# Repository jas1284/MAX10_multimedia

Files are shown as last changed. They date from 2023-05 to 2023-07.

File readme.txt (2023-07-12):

Uncompressed* Audio and Video playback on DE10-lite MAX10 FPGA board.
Requires an arduino shield with microSD slot via SPI.
(UIUC ECE385 SP23 final project)

DEMO VIDEO:
https://youtu.be/Ck-EtcvA4ko

HOW TO USE THIS PROJECT
Compile and run with Quartus Prime Lite 18.1.
Simply open FP-ZUOFU-BASIC.qsf and compile. "player_toplevel" should be top level.
Program the FPGA, no eclipse needed because no NIOS. (Custom I2C module inits the SGTL5000!)

Load in your SDcard and hit reset. Enjoy!

Controls:
- KEY0 is reset/reload. Press this button if you change out the SDcard or switch between audio and video modes (SW9).
   - The FPGA will first buffer half of the SDRAM, and then begin playback. The rest is loaded while playing.
   - While buffering, HEX5:HEX0 will display the address being buffered to. 
- KEY1 is volume adjust. It adjusts volume circularly, and works by writing to the SGTL's registers.
- SW1: set 1 to listen to audio playback, set 0 to listen to audio passthru from line in. 
- SW9: set 1 to play y4m video, set 0 to play wav audio.

Outputs:
- LEDR 9,8 indicate SDcard buffer load status. When both lit, the SDCard has stopped writing to buffer since it's half is done.
    - If only LEDR9 is on, this indicates that the buffer has been overrun, and the video playback will probably loop in a bit.
    - This is because the ping-pong buffer only allows writes to the half that reads are NOT being read from.
- LEDR 7,6 are debug indicators for video playback.

Loading a file to SDCARD
- Make sure you are using an SDHC card.
- Download and install HXD - run it as administrator (following step may fail otherwise)
- Open the SDcard as a RAW DISK (tools, open disk, physical disks - uncheck readonly)

VIDEO: Use the .bat file included. Needs FFMPEG, available online.
- Open the output.y4m in HxD
- CTRL-A the contents of output.y4m, paste it to the SDCard at address 0.
- Copy starting from the first "FRAME" of output.y4m, and paste it starting at address 0x59.
   - "F" of "FRAME" should be at 0x59.
   - Playback will work if you do not do this step (my code is flexible), 
      but the SDRAM ping-pong buffer may run erratically and fail to buffer in time.
      - The SDCARD throughput bottleneck is real!
      - My guess is that the SDcard's delays when moving from one block to the next happen to occur
        at lucky times when starting from 0x59, while starting anywhere else leads to unlucky delay timing 
        that ultimately results in not refilling the buffer in time. 
- Ctrl-S to save to the SDcard - this may take a while.
- Eject the card, put it in the FPGA, set SW9 to 1, hit reset, enjoy.
- Slow SDcards may not be fast enough for video playback even with the 0x59 start. 
- SANDISK EXTREME 32GB were our card of choice, but they were only barely just fast enough.
    - Old SANDISK 32GB ULTRA PLUS was ever so slightly too slow for video, but plenty fast for audio.
HEX0 will show format being detected:
- 4: y4m (YUV420P, 176x144 @ 24fps)
- 1: H.261 (incomplete/inoperable, sadly)
HEX5:HEX1 will show the current leftmost contents of the playback shift-register.

AUDIO: Open your desired file in Audacity, export in one of 3 WAV formats @ 44.1khz:
- 16bit signed PCM
- "U-law" (8bits mapping to 14bits)
- "A-law" (8bits mapping to 13bits)

- Open the file in HxD
- Ctrl-A the contents and paste it to SDCARD at address 0.
(No special offsets needed here - audio bitrate is low and forgiving.)
- Ctrl-S to save the contents to the card. This may take a moment.
- Eject the card, put it in the FPGA, set sw9 to 0, hit reset, enjoy. Plug in VGA for visualizer!
- FPGA auto-detects the playback format. 
HEX0 will show what it's detecting:
- 1: 16-bit signed PCM (stereo)
- 2: U-law (stereo)
- A: A-law (stereo)
HEX5:HEX1 will show what the current playback address[23:4] in memory is.

.VOX VOX ADPCM and MONO IMA-ADPCM in WAV are both experimental and very rough support. 
Playback amplitude erratic but the sound is identifiable.

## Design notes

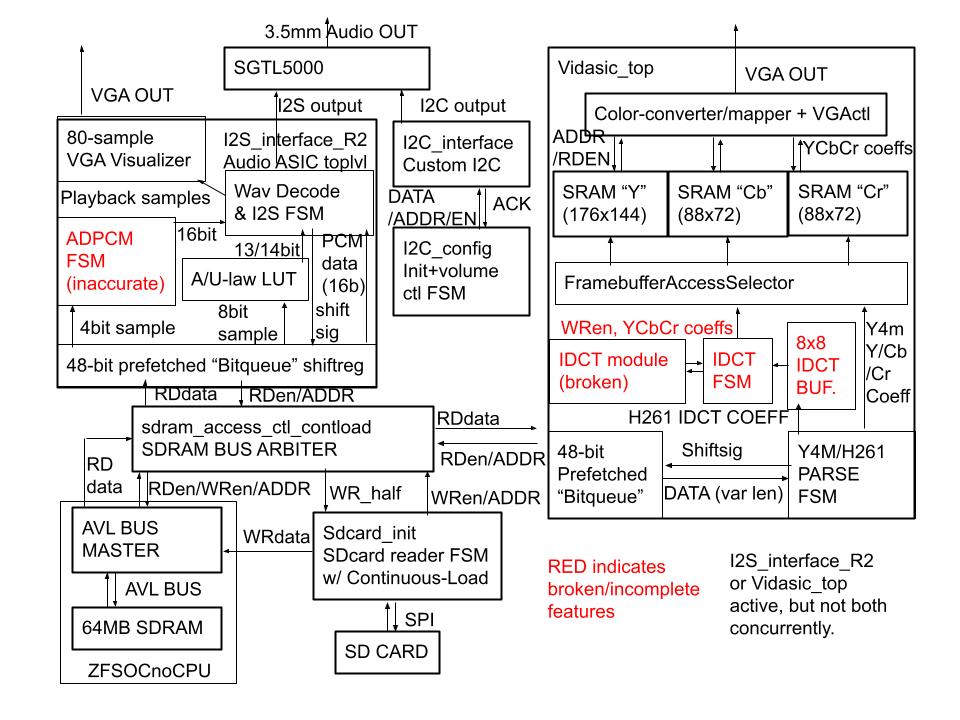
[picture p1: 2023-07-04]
BlockDiagram.jpg

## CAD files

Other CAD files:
stp2.stp
stp3.stp
stp1.stp

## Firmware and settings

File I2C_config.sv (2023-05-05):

// Module for storing and writing the intial configurations for the audio registers on the SGTL5000 and continually updating volume
// Takes input of clk, reset, an acknowledge from the I2C_interface, and a switch or button. Upon program startup or reset, it will
// write to the registers so that audio is outputting from I2S to HP out, and it will continue to loop, updating volume through switch
// input and writing it to the register on the SGTL5000.

module I2C_config (
	input  logic clk50,
	input  logic reset,
	
	output logic [15:0] i2c_address,
	output logic [15:0] i2c_data,
	output logic interface_enable,
	
	input  logic interface_acknowledge,	
	
	//volume:
	input  logic SW1
	);
	
	
	logic [3:0] counter_state = 0;
	logic interface_acknowledge_state = 0;
	
	logic SW1_state = 1;
	logic ack_state = 0;
	
	logic [5:0] clk50_counter = 0;
	logic [5:0] pulselength = 50;
	logic [6:0] volume = 0;
	
	//just trigger 
	always_ff @ (posedge clk50) begin
		counter_state <= counter_state;
		interface_enable <= 1'b0;
		volume <= volume;
		//need rising edge of interface_acknowledge and being within correct range to increment/output data
		if(interface_acknowledge == 1'b1 && interface_acknowledge_state == 1'b0 && counter_state < 12) begin
			interface_acknowledge_state <= 1'b1;
			interface_enable <= 1'b1;
		end
		//cycle through all the states (each state is just data to output for config
		if(interface_acknowledge == 1'b0 && interface_acknowledge_state == 1'b1) begin
			if(counter_state < 11) begin
				counter_state <= counter_state + 1;
			end//last state loops and constantly writes the value of volume to the I2C config
			interface_acknowledge_state <= 1'b0;
		end
		
		if(reset) begin //resets state to 0 and restarts the config cycle
			interface_acknowledge_state <= 1'b0;
			counter_state <= 0;
			interface_enable <= 1'b0;
		end
		
		if(SW1 == 1 && SW1_state == 0) begin //switch edge detection for volume value update
			SW1_state <= 1;
			if(volume >= 120) begin
				volume <= 0;
			end
			else begin
				volume <= volume + 20;
			end
		end
		
		if(SW1 == 0 && SW1_state == 1) begin
			SW1_state <= 0;
		end
	end
	
	
	
	//i2c_address and i2c_data output
	//See datasheet and report for specifics of what each write does, for the most part it is the same as provided code
	//except changing a few minor values like # of bits per cycle
	always_comb begin
		i2c_address = 16'h0000;
		i2c_data = 16'h0000;
		case (counter_state) 
			1: begin
				//CHIP_PLL_CTRL register: 739b 
				i2c_address = 16'h0032;
				i2c_data = 16'h739b;
			end
			2: begin
				//CHIP_ANA_POWER register: 45fe
				i2c_address = 16'h0030;
				i2c_data = 16'h45fe;
			end
			3: begin
				//CHIP_REF_CTRL register: 4e
				i2c_address = 16'h0028;
				i2c_data = 16'h004e;
			end
			4: begin
				//CHIP_DIG_POWER register: 63
				i2c_address = 16'h0002;
				i2c_data = 16'h0063;
			end
			5: begin
				//CHIP_CLK_CTRL register: 7
				i2c_address = 16'h0004;
				i2c_data = 16'h0007;
			end
			6: begin
				//CHIP_I2S_CTRL register: b0
				i2c_address = 16'h0006;
				i2c_data = 16'h00b0;
			end
			7: begin
				//CHIP_ANA_CTRL register: 4
				i2c_address = 16'h0024;
				i2c_data = 16'h0004;
			end
			8: begin
				//CHIP_SSS_CTRL register: 10
				i2c_address = 16'h000a;
				i2c_data = 16'h0010;
			end
			9: begin
				//CHIP_ADCDAC_CTRL register: 0
				i2c_address = 16'h000e;
				i2c_data = 16'h0000;
			end
			10: begin
				//CHIP_PAD_STRENGTH register: 555f
				i2c_address = 16'h0014;
				i2c_data = 16'h555f;
			end
			11: begin//volume, continuously write at this address
				i2c_address = 16'h0022; 
				i2c_data = {1'b0, volume, 1'b0, volume};
			end
			default: ;
		endcase
	end
	
	
	
/*
address <= 32'h0022;
				byte_enable <= 4'b1111;
				write <= 1'b1;
				write_data <= ((volume << 8) || volume);
*/
endmodule

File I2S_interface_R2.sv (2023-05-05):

/*
-------------
Upon being enabled, I2S_interface will start reading a raw PCM data
from given starting address and using it to output formatted I2S 
as required by the SGTL5000.
-------------
*/
module I2S_interface_R2 (
	input 	logic clk50,
	input 	logic reset,
	// input 	logic run,
	//inputs for muxing
	
	output 	logic [24:0]	ADDR_PRGM, //address for read to program. Formatted as 1 address space per 16 bits.
	input  	logic [15:0]	RDdata_PRGM, //data for read to program
	output 	logic RDen,					 //read enable from program. 
	input 	logic avalon_bridge_acknowledge,
	
	
	output logic I2S_DIN, //data input
	input  logic I2S_LRCLK, //frame clock (input from master mode, 44.1 kHz)
	input  logic I2S_SCLK, //bit clock (input from master mode, 64 * frame  clk rate)
	
	
	input  logic ADDR_load, // enable loading ADDR_start, not implemented for now
	input  logic I2S_enable,
	input  logic [24:0] ADDR_start, //address to start sequentially reading from, not implemented for now
	output logic [3:0] hex_out_5,
    output logic [3:0] hex_out_4,
	output logic [3:0] hex_out_3,
	output logic [3:0] hex_out_2,
	output logic [3:0] hex_out_1,
	output logic [3:0] hex_out_0,
	output logic [3:0] red,
    output logic [3:0] green,
    output logic [3:0] blue,
    output logic hsync,
    output logic vsync
	);
	
	// logic LRCLK_state; //used to determine when LRCLK changes edge for reading
	// logic [5:0]  load_counter; //  = 5'b11111; 
	// logic [15:0] RDdata_buffer; // = 0; //to store result after a read
	// logic [24:0] ADDR_current; // = 25'h13C;	//0
	// logic [4:0]  write_counter; //  = 16;
	// logic endian = 1;
	
	// assign hex_out_0 = READ_ADDR[3:0];
	assign hex_out_1 = READ_ADDR[7:4];
	assign hex_out_2 = READ_ADDR[11:8];
	assign hex_out_3 = READ_ADDR[15:12];
	assign hex_out_4 = READ_ADDR[19:16];
	assign hex_out_5 = READ_ADDR[23:20];

	parameter BIT_DEPTH = 16;	// Assume this much, lol. We don't have a good way to deal with it otherwise!
	parameter VOLUME_SHIFT = 1; // how many bits to shift to preserve hearing?

	enum logic [12:0] 
    {q_shift, 
    q_shift_release, 
    q_prefetch,
    q_prefetch_release,
    q_load1, 
    q_load1_wait, 
    q_load2, 
    q_load2_wait, 
    q_load3, 
    q_load3_wait
    } queue_state, q_nextstate;

	logic [24:0]    READ_ADDR, READ_ADDR_NEXT;  // current address of read from buffer.
	// logic [15:0]    READ_WORD;  // word to load into queue
	logic [5:0]     SHIFTCOUNT, SHIFTCOUNT_NEXT; // keeps track of how many shifts happened.
	logic [47:0]    BITQUEUE, BITQ_NEXT;    // queue of bits coming in
	logic Q_RDY; // Is the queue safe to read from? 

	// Values for Ram buffering logic
	logic RAM_DATA_BUFFER_EN; // Flag for enabling the RAM_DATA_BUFFER.
	// logic RAM_DATA_RDEN;	// RDEN for the ram buffering logic... synonymous with the state it seems
	reg RAM_DATA_BUFFER_STATE; // Buffered state for operation of RAM data buffer. 
	logic [15:0]    RAM_BUFFERED_READBACK;

	// Ram readback buffering mechanism - makes sure we don't miss data.
	always_ff @ (posedge clk50 or posedge reset)
	begin
		if(reset)
		begin
			// RAM_DATA_RDEN <= 1'b0;
			RAM_BUFFERED_READBACK <= 16'h0;
			RAM_DATA_BUFFER_STATE <= 1'b0;  // state: inactive
		end
		else if(RAM_DATA_BUFFER_STATE)  // If active state...
		begin
			// RAM_DATA_RDEN <= 1'b1;
			if(avalon_bridge_acknowledge) begin
				RAM_BUFFERED_READBACK <= RDdata_PRGM;
				RAM_DATA_BUFFER_STATE <= 1'b0; // go back to inactive/unarmed state.
			end
		end
		else	// Inactive state
			// RAM_DATA_RDEN <= 1'b0;
			RAM_DATA_BUFFER_STATE <= RAM_DATA_BUFFER_EN;    // Wait to be activated.
	end

	logic RDEN_override;
	// assign RAM_DATA_RDEN = RAM_DATA_BUFFER_STATE;
	assign RDen = (RAM_DATA_BUFFER_STATE |RDEN_override);

	always_ff @ (posedge clk50 or posedge reset)
	begin
		if(reset)
		begin
			BITQUEUE <= 48'h0;
			SHIFTCOUNT <= 6'h0;
			queue_state <= q_load3;
			READ_ADDR <= 25'h00;    // 0x0A gets us to byte d20, which determines datatype
		end
		else if(I2S_enable)
		begin
			BITQUEUE <= BITQ_NEXT;
			SHIFTCOUNT <= SHIFTCOUNT_NEXT;
			queue_state <= q_nextstate;
			READ_ADDR <= READ_ADDR_NEXT;
		end
	end

	always_comb 
	begin
		// default values: 
		BITQ_NEXT = BITQUEUE;       // queue doesnt move
		READ_ADDR_NEXT = READ_ADDR; // addr doesnt change
		SHIFTCOUNT_NEXT = SHIFTCOUNT;   // shift-counter stays
		ADDR_PRGM = READ_ADDR;       // Pre-set the ram address
		RDEN_override = 1'b0; 
		q_nextstate = queue_state;  // stay in current state
		// status_1 = 1'b0;    // lights - blank em 
		// status_2 = 1'b0;
		Q_RDY = 1'b0;   // Assume the queue's NOT READY unless otherwise stated.
		RAM_DATA_BUFFER_EN = 1'b0;  // Ram buffering mechanism assumes no incoming data.
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

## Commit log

2023-04-19 SDRAM access state machine, janky prefetched bit-queue, and groundwork for beginning to interpret the bitstream
    [stp1.stp]
2023-04-20 loading up to first TCOEFF
    [stp1.stp]
2023-04-24 audio smashed on but not really functional, will re-write
    [stp1.stp, stp2.stp]
2023-04-25 rewrote I2S interface to actually work
    [stp2.stp]
2023-04-25 buggy implementation, audio queue desyncs
    [sdcard_init.sv]
2023-04-26 temp pause... circular buffer screwed up
    [stp2.stp]
2023-04-26 stabilized audio output, by relying on slightly less questionable logic
    [stp2.stp]
2023-04-26 added bit-shift volume parameter to preserve eardrums
    [stp2.stp]
2023-04-27 SDRAM CIRCULAR LOAD COMPLETE
    [stp2.stp]
2023-04-27 added format checking
    [stp2.stp]
2023-04-27 saving progress - somehow broke PCM
    [stp2.stp]
2023-04-27 PCM un-broken? was it ever broken?
    [stp2.stp]
2023-04-27 A-LAW COMPRESSION WORKING - and bugs with ADPCM may be I2S related not ADPCM's fault.
    [stp2.stp]
2023-04-27 LISTENABLE BUT BAD VOX-ADPCM PLAYBACKgit status!
    [stp2.stp]
2023-04-28 A-law perfected - forgot to negate bits in accordance with standard. u-law probably also fixed.
    [I2S_interface_R2.sv]
2023-04-28 implemented adjustable volume and imperfect MONO IMA-ADPCM (WAV) playback
    [stp2.stp]
2023-04-30 rework of YCBCR to observe verilog sign quirks
    [I2S_interface_R2.sv, vidasic_top.sv]
2023-04-30 small ADPCM bug fixed but still buggy
    [I2S_interface_R2.sv]
2023-04-30 IMA-adpcm still bad but at least largely recognizable. can't spend too much time on it.
    [I2S_interface_R2.sv]
2023-04-30 modernized the bitqueue for video
    [stp1.stp]
2023-05-01 UNCOMPRESSED VIDEO WATCHABLY WORKING - YUV420P Y4M
    [stp3.stp]
2023-05-01 near perfect YUV420P playback
    [stp3.stp]
2023-05-01 seamless playback of 15fps stabilized. could be worse, could be better.
    [stp3.stp]
2023-05-01 TUNED FOR 24FPS, BARELY!
    [stp3.stp]
2023-05-02 fixed color errors by clipping RGB values
    [stp3.stp]
2023-05-02 loading indicator added for verifying missed buffer loads
    [sdcard_init.sv, vidasic_top.sv]
2023-05-02 all playback/color/offset bugs fixed
    [vidasic_top.sv]
2023-05-02 found a way to standardize video playback and it's fucking stupid
    [stp3.stp]
2023-05-03 halt on invdct, taurine cylinders ineffective
2023-05-04 removed NIOS, implemented benjamin's HW I2C Init for SGTL
    [stp1.stp]
2023-05-04 IDCT in progress, hardware volume control added by benjamin. Possibly last pre-demo commit.
    [stp1.stp]
2023-05-05 Add comments to I2C_config
    No changes to functional code
2023-05-05 Add Comments to I2C_interface
    No functional code changes made
2023-05-05 added comments
    [stp1.stp]
2023-06-10 minor color modifications - attempts to average colors. no further idct work
    [stp2.stp, stp3.stp]
